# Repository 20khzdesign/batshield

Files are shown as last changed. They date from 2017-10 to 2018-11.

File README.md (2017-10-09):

Batshield
=========

An audio shield for arduino intended to develop audio synthesis and filtering.

Features
========

- MIDI input
- MIDI output
- Mic/Line input
- Line output
- 2 PWM output
- 4 switches
- 4 push buttons
- 5 knobs

The line output have been designed in order to be compatible with mozzi library
(http://sensorium.github.io/Mozzi/)

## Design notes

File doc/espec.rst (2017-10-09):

Batshield
=========

Alcance
-------
Diseño y construcción de un escudo para arduino orientado al desarrollo de
aplicaciones de audio.

Especificaciones
----------------

- Escudo para Arduino Uno.

- Entradas de señal:
  - line in (aprox 1V)
  - mic in (aprox 50mV)
  - midi in

- Salidas de señal:
  - line out (mono)
  - midi out
  
- Controles:
  - varios knobs
  - varios interruptores
  - varios pulsadores
  
- Alimentación:
  - El propio arduino alimenta al escudo.

- Las conexiones de las entradas y salidas a los pines de arduino se podrán
  definir por configuración.
  
- alarma luminosa si la configuración es incorrecta.

- Maximizar el nº de controles según los pines disponibles de arduino.

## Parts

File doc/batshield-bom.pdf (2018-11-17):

Ref | Qty | Value | Footprint | Datasheet
C1 | 1 | 270p | Capacitors_THT:C_Disc_D5.0mm_W2.5mm_P5.00mm
C2 C4 | 2 | 4.7u | Capacitors_THT:CP_Radial_D5.0mm_P2.50mm
C3 | 1 | 0.1u | Capacitors_THT:C_Disc_D5.0mm_W2.5mm_P5.00mm
C5 C6 | 2 | 0.1n | Capacitors_THT:C_Disc_D5.0mm_W2.5mm_P5.00mm
C7 | 1 | 4.7n | Capacitors_THT:C_Disc_D5.0mm_W2.5mm_P5.00mm

# BATSHIELD BOM REV 0.1 (https://creativecommons.org/licenses/by-sa/4.0/)

DATE
2001-01-01

COMPANY
20khzdesign - Juanda Rodríguez

COMMENT 1
Arduino shield for audio
applications

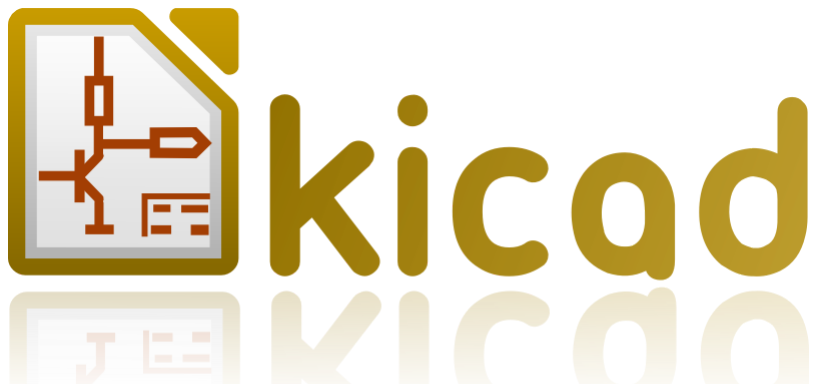
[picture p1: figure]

COMMENT 2
https://creativecommons.org/licenses/by-sa/4.0/

COMMENT 3
Creative Common. Attribution-ShareAlike 4.0 International (CC BY-SA 4.0)
COMMENT 4 | TOTAL PARTS
| 65 (Unique 43)

# [C] - Capacitors

Create PDF in your applications with the Pdfcrowd HTML to PDF API (https://pdfcrowd.com/doc/api/?ref=pdf) | PDFCROWD (https://pdfcrowd.com/?ref=pdf)

C8 C9 | 2 | 220n | Capacitors_THT:C_Disc_D5.0mm_W2.5mm_P5.00mm
C10 | 1 | 1n | Capacitors_THT:C_Disc_D5.0mm_W2.5mm_P5.00mm
C11 | 1 | 100n | Capacitors_THT:C_Disc_D5.0mm_W2.5mm_P5.00mm
D1 | 1 | 1N4148 | Diodes_THT:D_DO- 35_SOD27_P7.62mm_Horizontal
J1 | 1 | I/O 1 | Pin_Headers:Pin_Header_Straight_1x03_Pitch2.54mm
J2 J5 | 2 | mic in 1/4'' | conectores:Jack_Female_6,35mm_HD
J3 | 1 | arduinoUnoPinout | arduino:arduinoUnoPinout
J4 | 1 | I/O 2 | Pin_Headers:Pin_Header_Straight_1x03_Pitch2.54mm
J6 | 1 | MIDI out | conectores:MIDI_female_5_pins
J7 | 1 | MIDI IN | conectores:MIDI_female_5_pins
R1 | 1 | 2k2 | Resistors_THT:R_Axial_DIN0207_L6.3mm_D2.5mm_P7.62mm_Horizontal
R2 R3 R6 | 3 | 100k | Resistors_THT:R_Axial_DIN0207_L6.3mm_D2.5mm_P7.62mm_Horizontal
R4 R5 R25 | 3 | 4k7 | Resistors_THT:R_Axial_DIN0207_L6.3mm_D2.5mm_P7.62mm_Horizontal
R7 R8 | 2 | 1M | Resistors_THT:R_Axial_DIN0207_L6.3mm_D2.5mm_P7.62mm_Horizontal
R9 | 1 | 499k | Resistors_THT:R_Axial_DIN0207_L6.3mm_D2.5mm_P7.62mm_Horizontal
R10 | 1 | 3.9k | Resistors_THT:R_Axial_DIN0207_L6.3mm_D2.5mm_P7.62mm_Horizontal
R11 | 1 | 270 | Resistors_THT:R_Axial_DIN0207_L6.3mm_D2.5mm_P7.62mm_Horizontal
R12 R13 | 2 | 680 | Resistors_THT:R_Axial_DIN0207_L6.3mm_D2.5mm_P7.62mm_Horizontal
R14 R15 R16 R18 R19 R20 | 6 | 10k | Resistors_THT:R_Axial_DIN0207_L6.3mm_D2.5mm_P7.62mm_Horizontal
R17 | 1 | 330 | Resistors_THT:R_Axial_DIN0207_L6.3mm_D2.5mm_P7.62mm_Horizontal

# [D] - Diodes

[J] -

# [R] - Resistors

R21 R22 R23 R24 | 4 | 220 | Resistors_THT:R_Axial_DIN0207_L6.3mm_D2.5mm_P7.62mm_Horizontal
RV1 | 1 | 100k | conectores:potenciometro_PTV09
RV2 RV3 RV4 RV5 RV6 | 5 | 10k | conectores:potenciometro_PTV09
SW1 | 1 | RESET | Buttons_Switches_THT:SW_PUSH_6mm_h5mm
SW2 | 1 | SW/HW SER R | conectores:interruptor_spdt
SW3 | 1 | SW/HW SER W | conectores:interruptor_spdt
SW4 | 1 | RUN/PROG | conectores:interruptor_spdt
SW5 | 1 | HIFI/LOFI | conectores:interruptor_spdt
SW6 | 1 | PWM/FILTERED | conectores:interruptor_spdt
SW7 | 1 | NORMAL/BRIGHT | conectores:interruptor_spdt
SW8 | 1 | SWT1 | conectores:interruptor_spdt
SW9 | 1 | SWT2 | conectores:interruptor_spdt
SW10 | 1 | SWT3 | conectores:interruptor_spdt
SW11 | 1 | BTN1 | conectores:button_spst
SW12 | 1 | BTN2 | conectores:button_spst
SW13 | 1 | BTN3 | conectores:button_spst
U1 | 1 | TL062 | Housings_DIP:DIP- 8_W7.62mm
U2 | 1 | 6N138 | Housings_DIP:DIP- 8_W7.62mm

[RV] -

[SW] -

# [U] - Semiconductors

BOM made with KICAD_BOM_WIZARD (https://github.com/HashDefineElectronics/KiCad_BOM_Wizard) (Generated martes, 23 '23e' enero '23e' 2018, 12:56:08)

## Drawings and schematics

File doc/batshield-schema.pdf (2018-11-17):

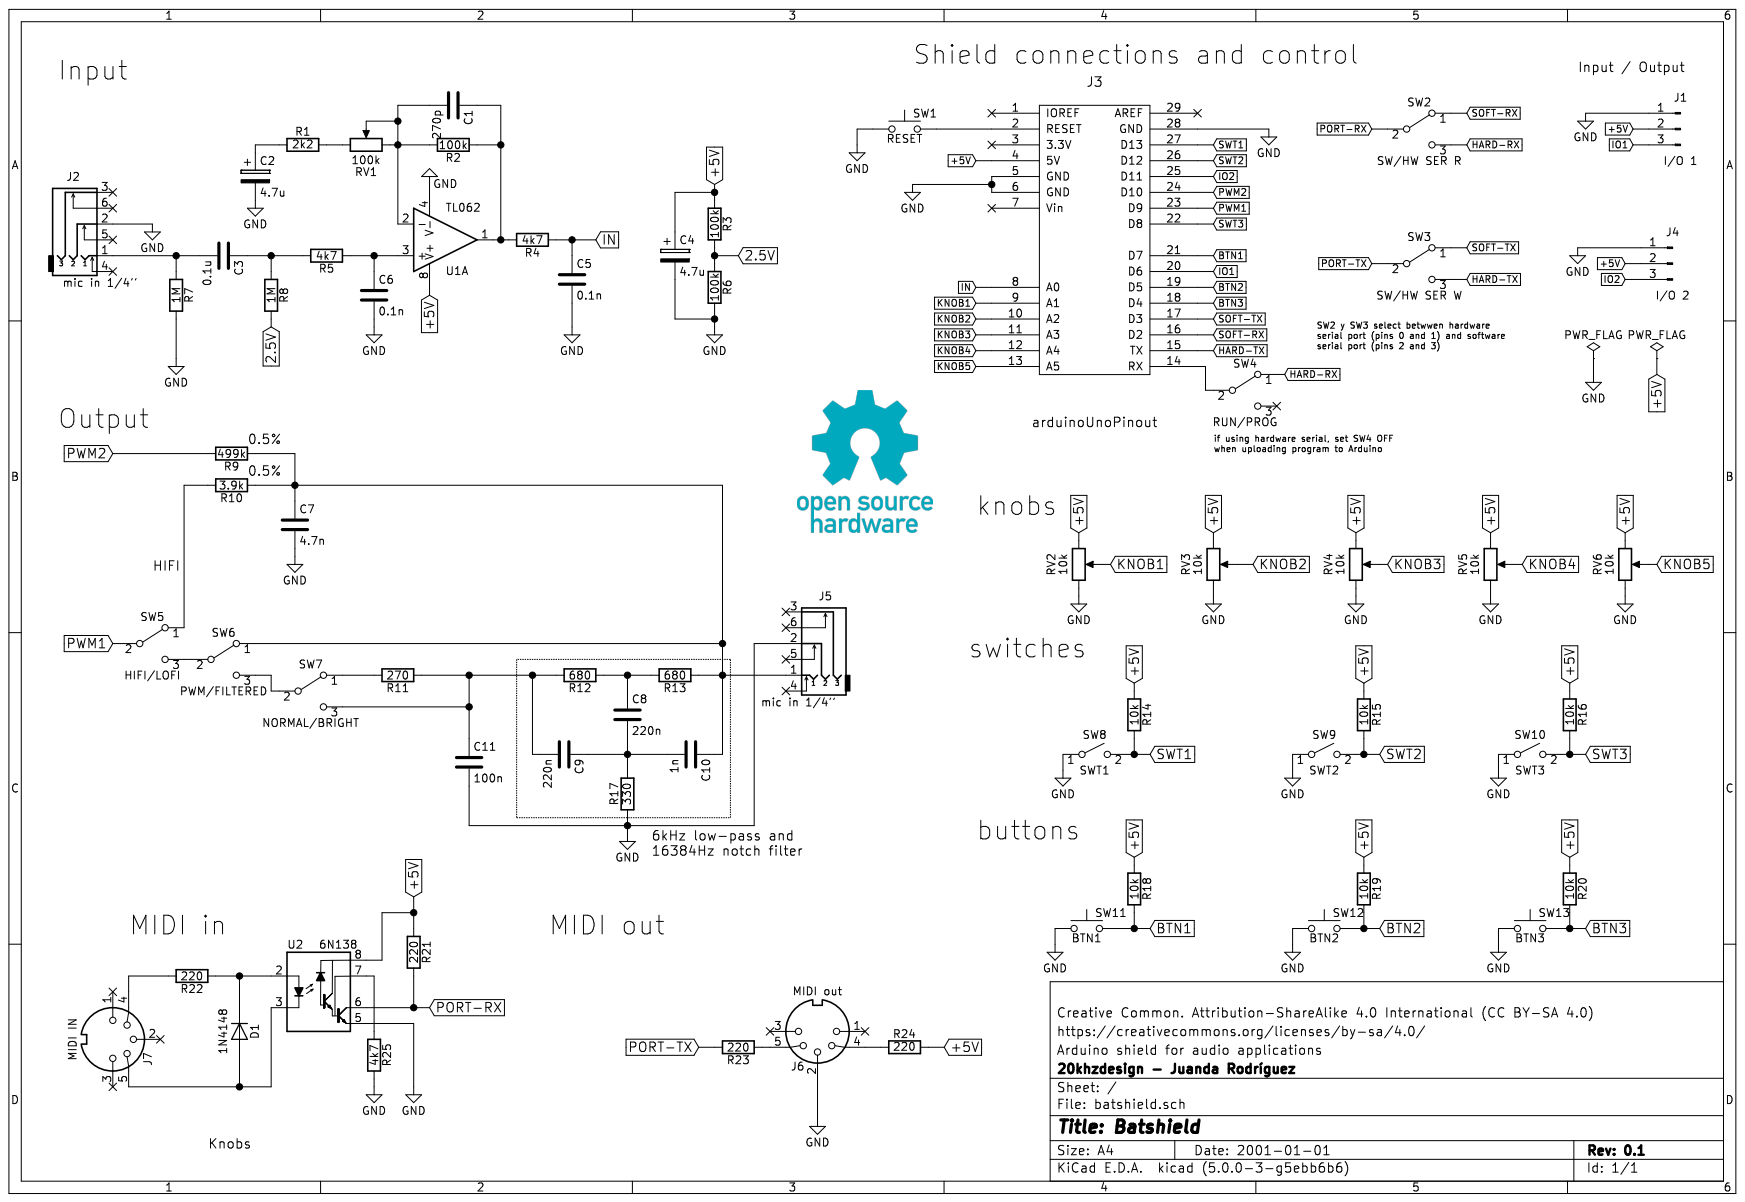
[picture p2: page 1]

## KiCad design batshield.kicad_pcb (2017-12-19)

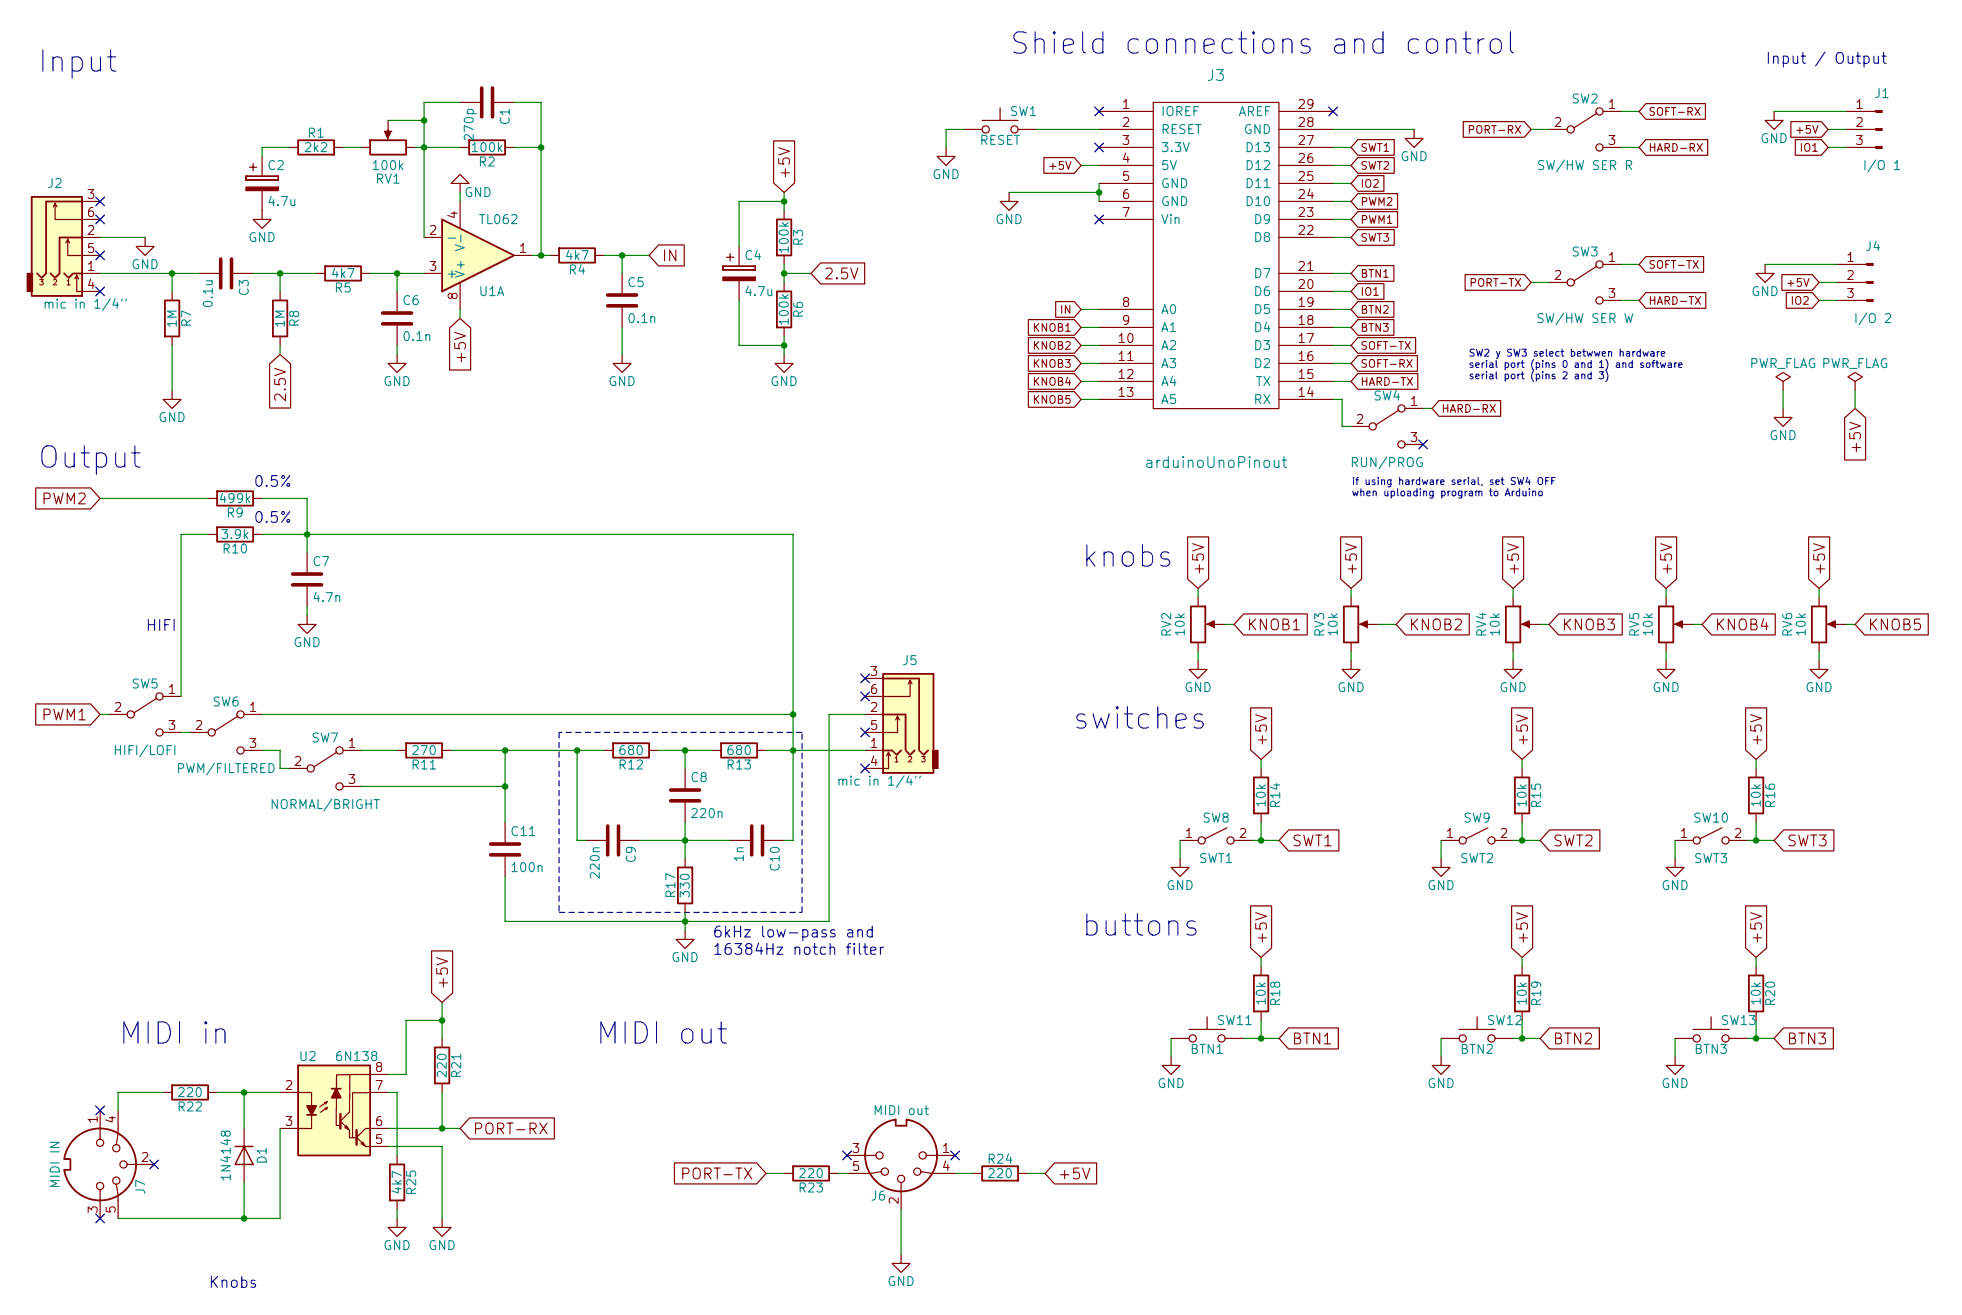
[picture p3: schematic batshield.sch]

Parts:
C1: 270p; C_Disc_D5.0mm_W2.5mm_P5.00mm
C2, C4: 4.7u; CP_Radial_D5.0mm_P2.50mm
C3: 0.1u; C_Disc_D5.0mm_W2.5mm_P5.00mm
C5, C6: 0.1n; C_Disc_D5.0mm_W2.5mm_P5.00mm
C7: 4.7n; C_Disc_D5.0mm_W2.5mm_P5.00mm
C8, C9: 220n; C_Disc_D5.0mm_W2.5mm_P5.00mm
C10: 1n; C_Disc_D5.0mm_W2.5mm_P5.00mm
C11: 100n; C_Disc_D5.0mm_W2.5mm_P5.00mm
D1: 1N4148; D_DO-35_SOD27_P7.62mm_Horizontal
J1: I/O 1; Pin_Header_Straight_1x03_Pitch2.54mm
J2, J5: mic in 1/4''; Jack_Female_6,35mm_HD
J3: arduinoUnoPinout
J4: I/O 2; Pin_Header_Straight_1x03_Pitch2.54mm
J6: MIDI out; MIDI_female_5_pins
J7: MIDI IN; MIDI_female_5_pins
R1: 2k2; R_Axial_DIN0207_L6.3mm_D2.5mm_P7.62mm_Horizontal
R2, R3, R6: 100k; R_Axial_DIN0207_L6.3mm_D2.5mm_P7.62mm_Horizontal
R4, R5, R25: 4k7; R_Axial_DIN0207_L6.3mm_D2.5mm_P7.62mm_Horizontal
R7, R8: 1M; R_Axial_DIN0207_L6.3mm_D2.5mm_P7.62mm_Horizontal
R9: 499k; R_Axial_DIN0207_L6.3mm_D2.5mm_P7.62mm_Horizontal
R10: 3.9k; R_Axial_DIN0207_L6.3mm_D2.5mm_P7.62mm_Horizontal
R11: 270; R_Axial_DIN0207_L6.3mm_D2.5mm_P7.62mm_Horizontal
R12, R13: 680; R_Axial_DIN0207_L6.3mm_D2.5mm_P7.62mm_Horizontal
R14, R15, R16, R18, R19, R20: 10k; R_Axial_DIN0207_L6.3mm_D2.5mm_P7.62mm_Horizontal
R17: 330; R_Axial_DIN0207_L6.3mm_D2.5mm_P7.62mm_Horizontal
R21, R22, R23, R24: 220; R_Axial_DIN0207_L6.3mm_D2.5mm_P7.62mm_Horizontal
RV1: 100k; potenciometro_PTV09
RV2, RV3, RV4, RV5, RV6: 10k; potenciometro_PTV09
SW1: RESET; SW_PUSH_6mm_h5mm
SW2: SW/HW SER R; interruptor_spdt
SW3: SW/HW SER W; interruptor_spdt
SW4: RUN/PROG; interruptor_spdt
SW5: HIFI/LOFI; interruptor_spdt
SW6: PWM/FILTERED; interruptor_spdt
SW7: NORMAL/BRIGHT; interruptor_spdt
SW8: SWT1; interruptor_spdt
SW9: SWT2; interruptor_spdt
SW10: SWT3; interruptor_spdt
SW11: BTN1; button_spst
SW12: BTN2; button_spst
SW13: BTN3; button_spst
U1: TL062; DIP-8_W7.62mm
U2: 6N138; DIP-8_W7.62mm

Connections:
2.5V: R3.2, R6.1, R8.2
+5V: C4.1, J1.2, J3.4 (5V), J4.2, R3.1, R14.1, R15.1, R16.1, R18.1, R19.1, R20.1, R21.1, R24.2, RV2.1, RV3.1, RV4.1, RV5.1, RV6.1, U1.8 (V+), U2.8
BTN1: J3.21 (D7), R18.2, SW11.2
BTN2: J3.19 (D5), R19.2, SW12.2
BTN3: J3.18 (D4), R20.2, SW13.2
GND: C2.2, C4.2, C5.2, C6.2, C7.2, C11.2, J1.1, J2.2, J3.5 (GND), J3.6 (GND), J3.28 (GND), J4.1, J5.2, J6.2, R6.2, R7.2, R17.1, R25.2, RV2.3, RV3.3, RV4.3, RV5.3, RV6.3, SW1.1, SW8.1 (A), SW9.1 (A), SW10.1 (A), SW11.1, SW12.1, SW13.1, U1.4 (V-), U2.5; also elsewhere on the board
HARD-RX: SW2.3 (C), SW4.1 (A)
HARD-TX: J3.15 (TX), SW3.3 (C)
IN: C5.1, J3.8 (A0), R4.1
IO1: J1.3, J3.20 (D6)
IO2: J3.25 (D11), J4.3
KNOB1: J3.9 (A1), RV2.2
KNOB2: J3.10 (A2), RV3.2
KNOB3: J3.11 (A3), RV4.2
KNOB4: J3.12 (A4), RV5.2
KNOB5: J3.13 (A5), RV6.2
unnamed: C1.1, R2.1, R4.2, U1.1
unnamed: C1.2, R2.2, RV1.2, RV1.3, U1.2 (-)
unnamed: C2.1, R1.1
unnamed: C3.1, R5.2, R8.1
unnamed 20: C3.2, J2.1, R7.1; also elsewhere on the board
unnamed: C6.1, R5.1, U1.3 (+)
unnamed: C8.1, R12.1, R13.2
unnamed 23: C7.1, C10.1, J5.1, R9.1, R10.1, R13.1, SW6.1 (A); also elsewhere on the board
unnamed: C8.2, C9.1, C10.2, R17.2
unnamed: C9.2, C11.1, R11.1, R12.2, SW7.3 (C)
unnamed: D1.1 (K), R22.1, U2.2
unnamed 27: D1.2 (A), J7.5, U2.3; also elsewhere on the board
unnamed: J3.2 (RESET), SW1.2
unnamed: J3.14 (RX), SW4.2 (B)
unnamed 44: J6.4, R24.1; also elsewhere on the board
unnamed 45: J6.5, R23.1; also elsewhere on the board
unnamed 49: J7.4, R22.2; also elsewhere on the board
unnamed: R1.2, RV1.1
unnamed: R10.2, SW5.1 (A)
unnamed: R11.2, SW7.1 (A)
unnamed: R25.1, U2.7
unnamed: SW5.3 (C), SW6.2 (B)
unnamed: SW6.3 (C), SW7.2 (B)
PORT-RX: R21.2, SW2.2 (B), U2.6
PORT-TX: R23.2, SW3.2 (B)
PWM1: J3.23 (D9), SW5.2 (B)
PWM2: J3.24 (D10), R9.2
SOFT-RX: J3.16 (D2), SW2.1 (A)
SOFT-TX: J3.17 (D3), SW3.1 (A)
SWT1: J3.27 (D13), R14.2, SW8.2 (B)
SWT2: J3.26 (D12), R15.2, SW9.2 (B)
SWT3: J3.22 (D8), R16.2, SW10.2 (B)

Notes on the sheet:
6kHz low-pass and 16384Hz notch filter
MIDI in
MIDI out
Knobs
HIFI
switches
Input / Output
Input
0.5%
Output
Shield connections and control
buttons
knobs
SW2 y SW3 select betwwen hardware serial port (pins 0 and 1) and software serial port (pins 2 and 3)
if using hardware serial, set SW4 OFF when uploading program to Arduino

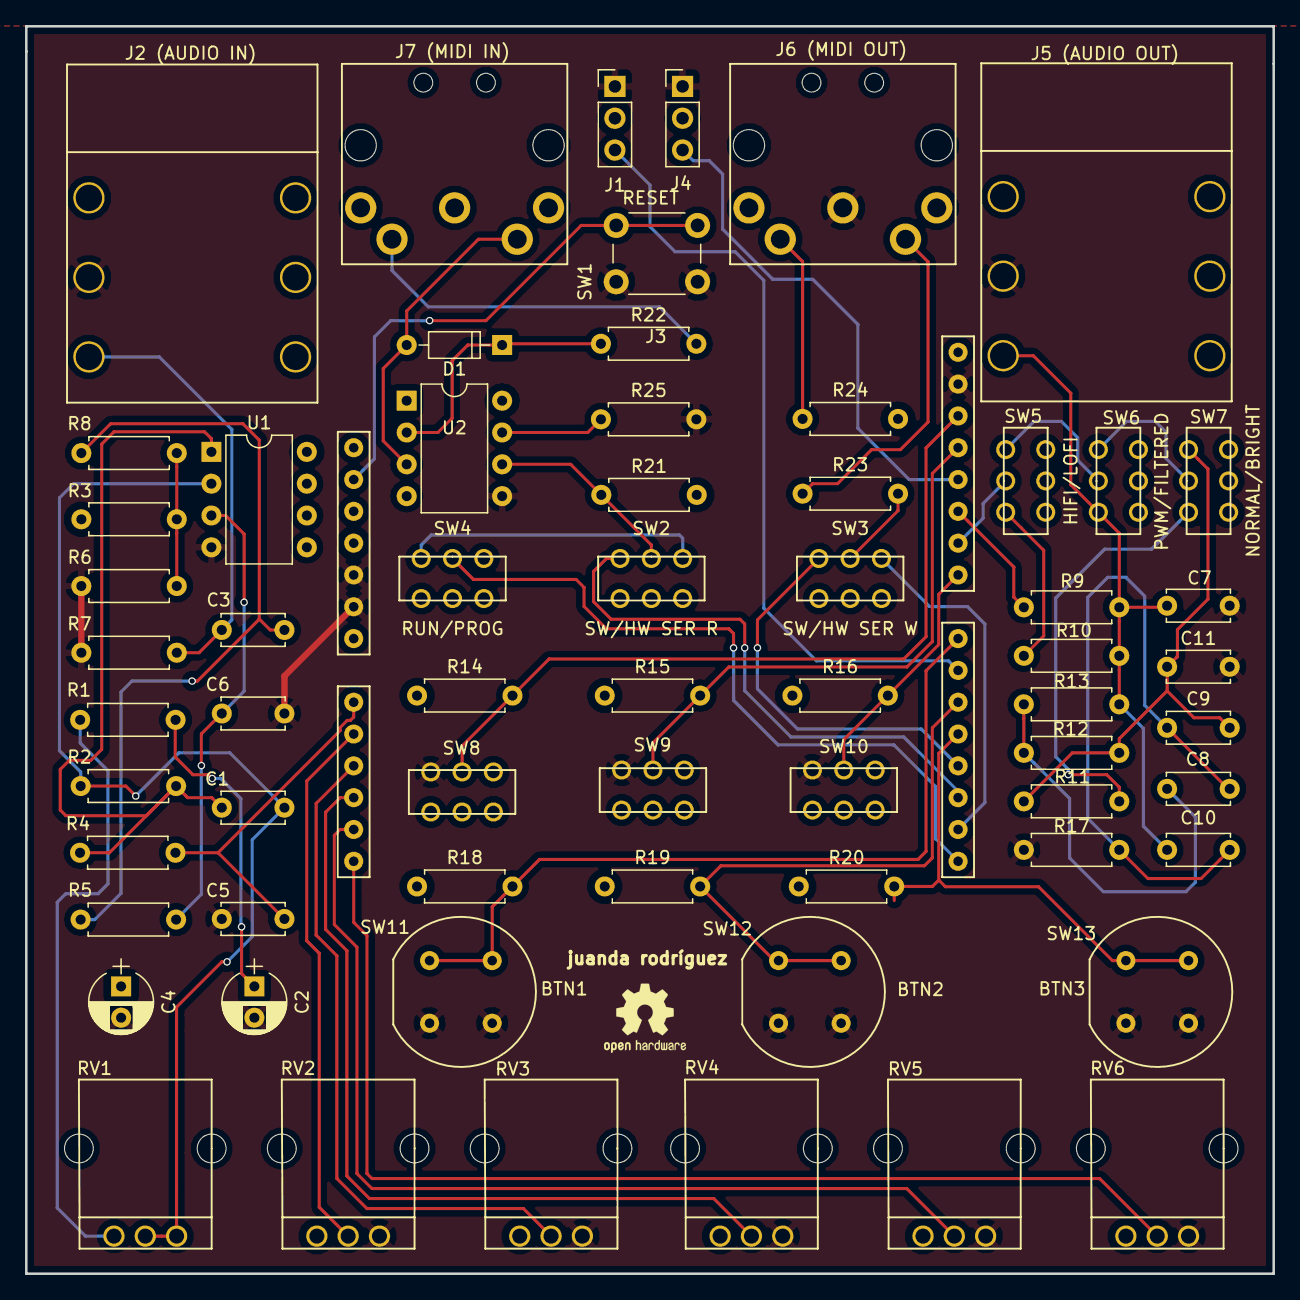
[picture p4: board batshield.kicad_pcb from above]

Board: 2 copper layers, 99.6 x 99.6 mm, 65 parts (0 on the bottom side), 48 nets.

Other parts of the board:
J2 (AUDIO IN), J5 (AUDIO OUT): mic in 1/4''; Jack_Female_6,35mm_HD
J6 (MIDI OUT): MIDI out; MIDI_female_5_pins
J7 (MIDI IN): MIDI IN; MIDI_female_5_pins

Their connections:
GND: J2 (AUDIO IN).2, J5 (AUDIO OUT).2, J6 (MIDI OUT).2; also elsewhere on the board
unnamed 20: J2 (AUDIO IN).1; also elsewhere on the board
unnamed 23: J5 (AUDIO OUT).1; also elsewhere on the board
unnamed 27: J7 (MIDI IN).5; also elsewhere on the board
unnamed 44: J6 (MIDI OUT).4; also elsewhere on the board
unnamed 45: J6 (MIDI OUT).5; also elsewhere on the board
unnamed 49: J7 (MIDI IN).4; also elsewhere on the board

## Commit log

2017-10-09 commit inicial
    [batshield.kicad_pcb, batshield.sch]
2017-10-09 todos los elementos añadidos
    [batshield.sch]
2017-10-09 power folags
    [batshield.sch]
2017-10-10 corrección salida audio
    [batshield.sch]
2017-10-13 preamp para guitarra
    [batshield.sch]
2017-10-15 simulaciones spice y preamplificador per tutto
    [batshield.sch]
2017-10-15 simulaciones spice y preamplificador per tutto ii
    [batshield.sch]
2017-10-16 listo para prototipo con breadboard
    [batshield.sch]
2017-11-16 mejoras, mejoras, mejoras
    [batshield.sch]
2017-11-21 pcb pasando drc
    [batshield.kicad_pcb, batshield.sch]
2017-11-25 añado algunos modelos 3d
    [batshield.kicad_pcb, batshield.sch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]
2017-11-25 quito transistor del circuito midi out
    [batshield.kicad_pcb, batshield.sch]
2017-12-17 reduciendo el tamaño de la placa unos milimetros cuadrados
    [batshield.kicad_pcb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]
2017-12-17 reduciendo el tamaño de la placa unos milimetros cuadrados ...
    [batshield.kicad_pcb]
2017-12-18 reducido a un tamaño aprox de 100mm x 100mm
    [batshield.kicad_pcb]
2018-11-17 añado Bill Of Materials
2018-11-17 cambio bom a doc
